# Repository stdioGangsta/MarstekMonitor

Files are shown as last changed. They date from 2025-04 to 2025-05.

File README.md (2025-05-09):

# MarstekMonitor

Small device with integrated display to monitor Marstek Venus battery systems.

Works on the 5.12kWh and 2.56kWh Marstek Venus battery.

Thanks to Superduper1969 and Tweakers (in Dutch) for EPSHome config and Modbus communication.

https://gathering.tweakers.net/forum/list_messages/2282240/0

WARNING:
Marstek has different versions of the Venus battery systems. The pinout of the RS485 connector is slightly different.
Currently, MarstekMonitor only supports Gen1 out of the box. Future versions will support all currently known models.

## Main features
-Plugs directly into the RS485 port on the side of the battery

-Easy configuration via ESPHome (and connection to Home Assistant)

-Display shows:

Battery Operating Mode (Idle, Charge, Discharge)

Charge/Discharge power

Battery SoC (State of Charge)

Charging Strategy (Auto, AI, Custom)

-No separate power supply needed

-(optional) Can be connected to WiFi to monitor/control the battery remotely (eg. Home Assisstant)\
The device is fully functional without a WiFi connection.

## What's in this repository?
#### Enclosure
Drawing of enclosure for the MarstekMonitor (behuizing) ( Both FreeCAD 0.21 and ready-to-3D-print .STL files)

#### HW
KiCAD 9.0 schematic and board files, including footprints for the used modules
#### SW
ESPHome yaml file

## HW v0.1
HW v0.1 is meant to be a proof of concept only. It consists of nothing more than a carrier board for the various modules.

09-04-2025: v0.1 assembled and working! There are a few minor issues that will be solved in the next version. See below.

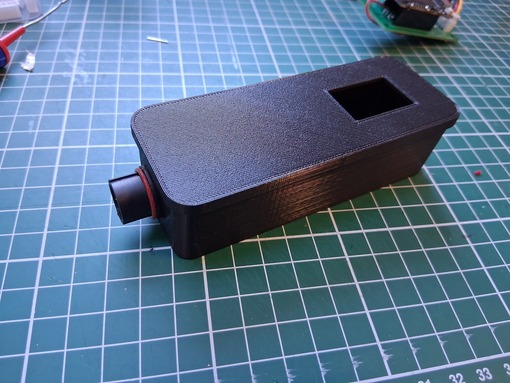
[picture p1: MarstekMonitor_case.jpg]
case

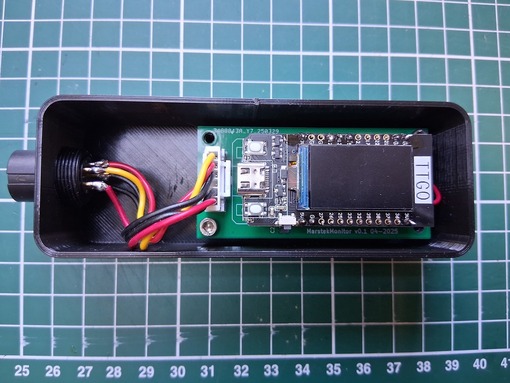
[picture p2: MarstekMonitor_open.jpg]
open

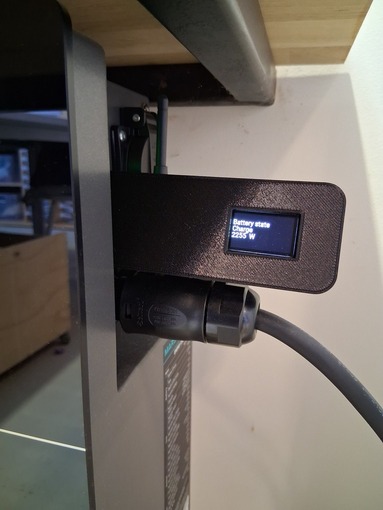
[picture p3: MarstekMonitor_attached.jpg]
attached


Partlist:
1. MarstekMonitor v0.1 PCB 
2. LilyGo ESP32 T-Display v1.1 [link](https://www.tinytronics.nl/en/development-boards/microcontroller-boards/with-wi-fi/lilygo-ttgo-t-display-v1.1-esp32-with-1.14-inch-tft-display "Webshop").
3. Buck-Boost converter [link](https://www.tinytronics.nl/en/power/voltage-converters/buck-boost-(step-up-down)-converters/dc-dc-step-up-down-buck-boost-converter-0.6a-5v-output "Webshop").
4. RS485-Serial module [link](https://nl.aliexpress.com/item/1005008217845791.html)
5. 3d Printed enclosure 
6. RS485 Connector: Weipu SP17, 5pin male connector. This connector is supplied with the Marstek battery

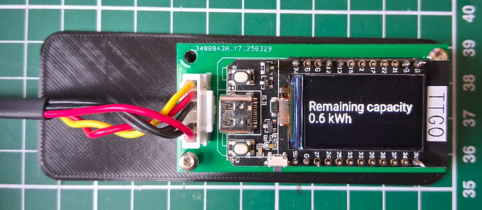
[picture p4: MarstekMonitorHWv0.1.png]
HW V0.1


### Known issues with HW v0.1
These will be solved in the next HW iteration
1. GPIO12 used for RS485. GPIO12 is an ESP32 strapping pin. This can cause issues on reset.
2. Switch to right-angle JST-XH connector
3. Footprint for Buck-boost and RS485 module: TH diameter slighty too small. Modules fit, but need to be forced in.
4. Silkscreen for Lilygo T-display does not match actual footprint
5. Panel mount Weipu 6p connector does not seem to exist.

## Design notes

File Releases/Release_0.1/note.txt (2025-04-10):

Release note for v0.1
!! v0.1 is not a stable release and is not recommended for end users !!

HW v0.1 contains no 3D printed enclosure and is only for proof-of-concept testing
The PCB has a known issue: The RX pin on T-DISPLAY ESP32 uses GPIO12. This is also a strapping pin and can lead to problems

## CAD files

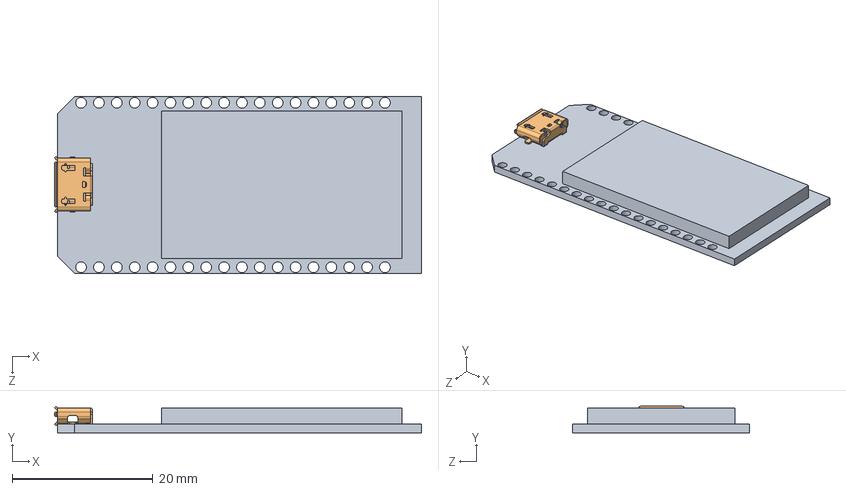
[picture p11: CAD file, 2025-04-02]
HW/ttgo-tdisplay-kicad-master/TTGO1.SLDASM
52.1 x 3.77 x 25.1 mm
TTGO-ESP32LORA
microusb

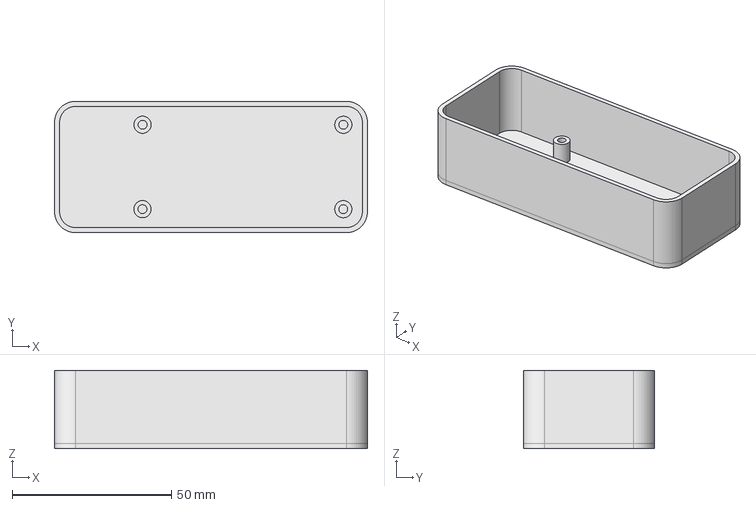
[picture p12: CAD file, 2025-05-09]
Enclosure/MarstekMonitorEnclosureV1.FCStd
98.2 x 41.2 x 24.6 mm

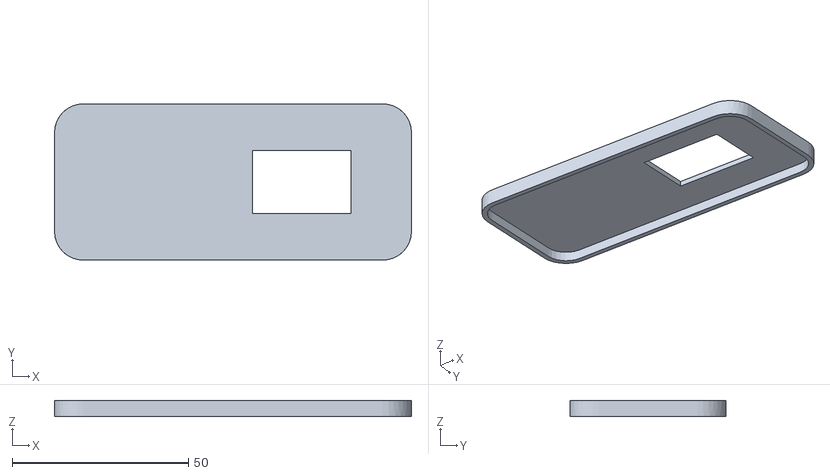
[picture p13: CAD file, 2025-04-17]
Enclosure/MarstekMonitorEnclosureV1Deksel.stl
101.4 x 44.4 x 4.60

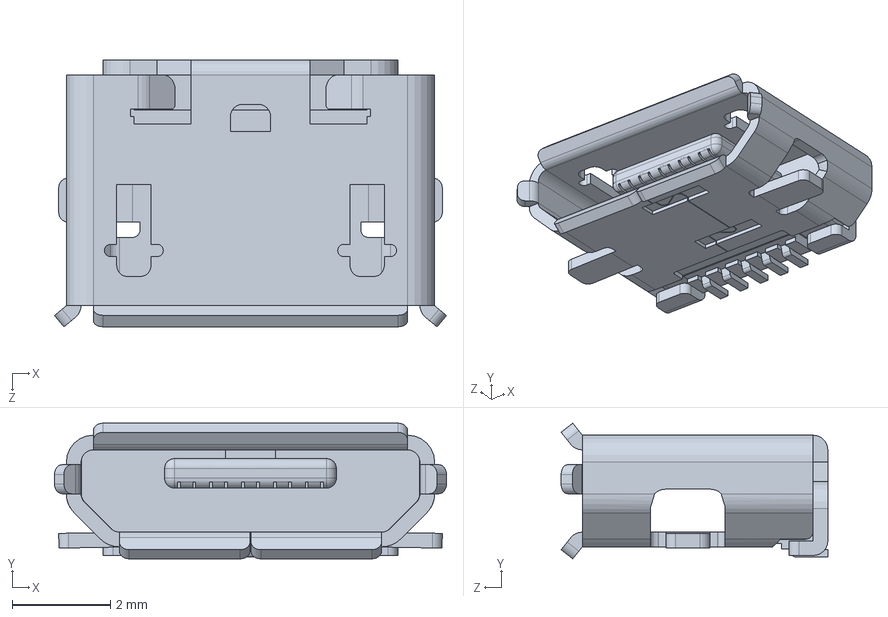
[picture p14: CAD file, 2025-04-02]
HW/ttgo-tdisplay-kicad-master/microusb.SLDPRT
7.98 x 2.76 x 5.43 mm

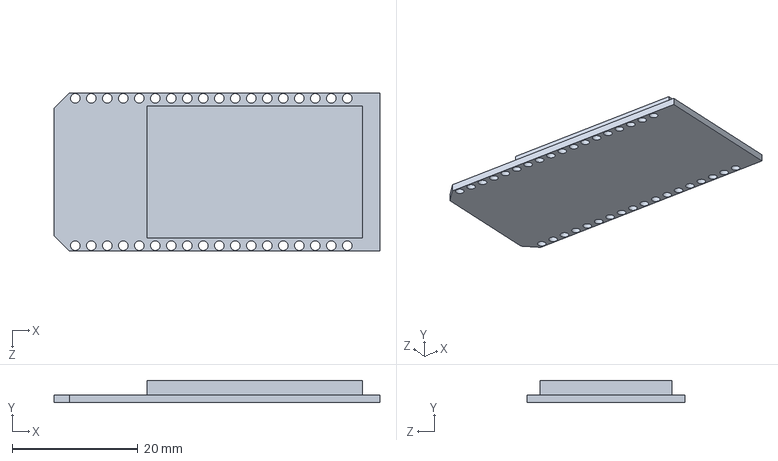
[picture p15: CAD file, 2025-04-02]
HW/ttgo-tdisplay-kicad-master/TTGO-ESP32LORA.SLDPRT
51.8 x 3.55 x 25.1 mm

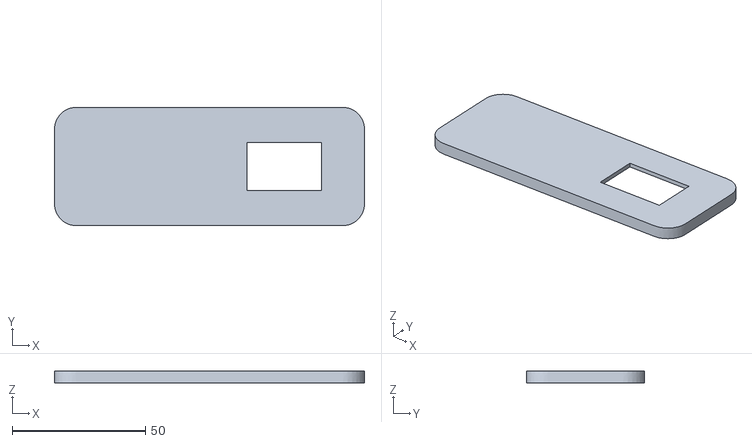
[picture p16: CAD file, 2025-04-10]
Enclosure/MarstekMonitorEnclosureV0Deksel.stl
116.4 x 44.4 x 4.60

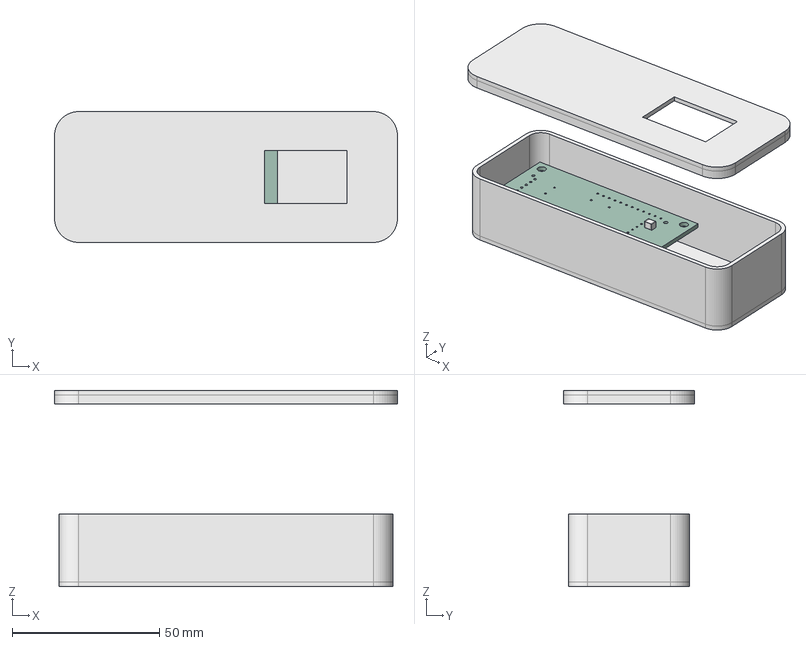
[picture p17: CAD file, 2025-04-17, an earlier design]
Enclosure/MarstekMonitorEnclosureV0.1.FCStd
116.4 x 44.4 x 66.6 mm
Doos
Deksel
C_1210_3225Metric
C_1210_3225Metric001
MarstekMonitor_PCB

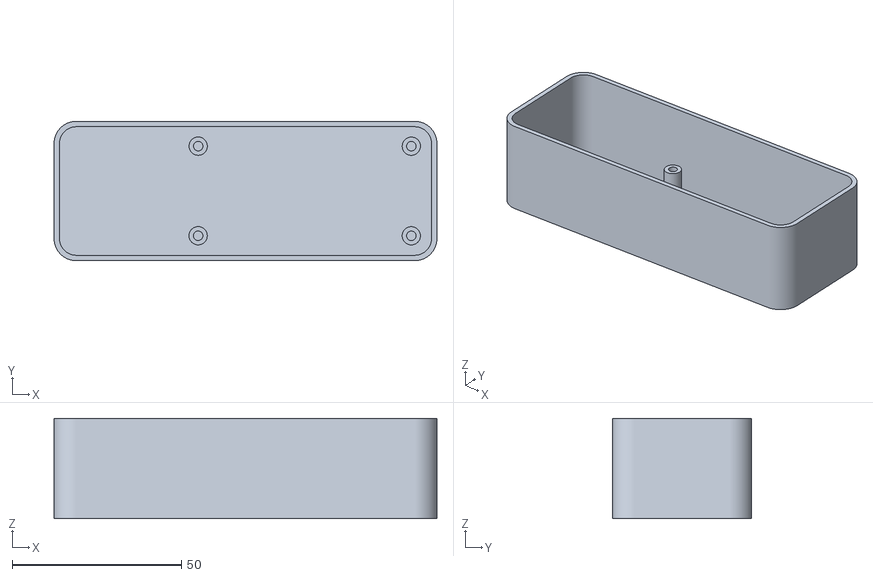
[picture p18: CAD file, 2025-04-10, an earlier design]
Enclosure/MarstekMonitorEnclosureV0.stl
113.2 x 41.2 x 29.6

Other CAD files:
Enclosure/MarstekMonitorEnclosureV1.stl

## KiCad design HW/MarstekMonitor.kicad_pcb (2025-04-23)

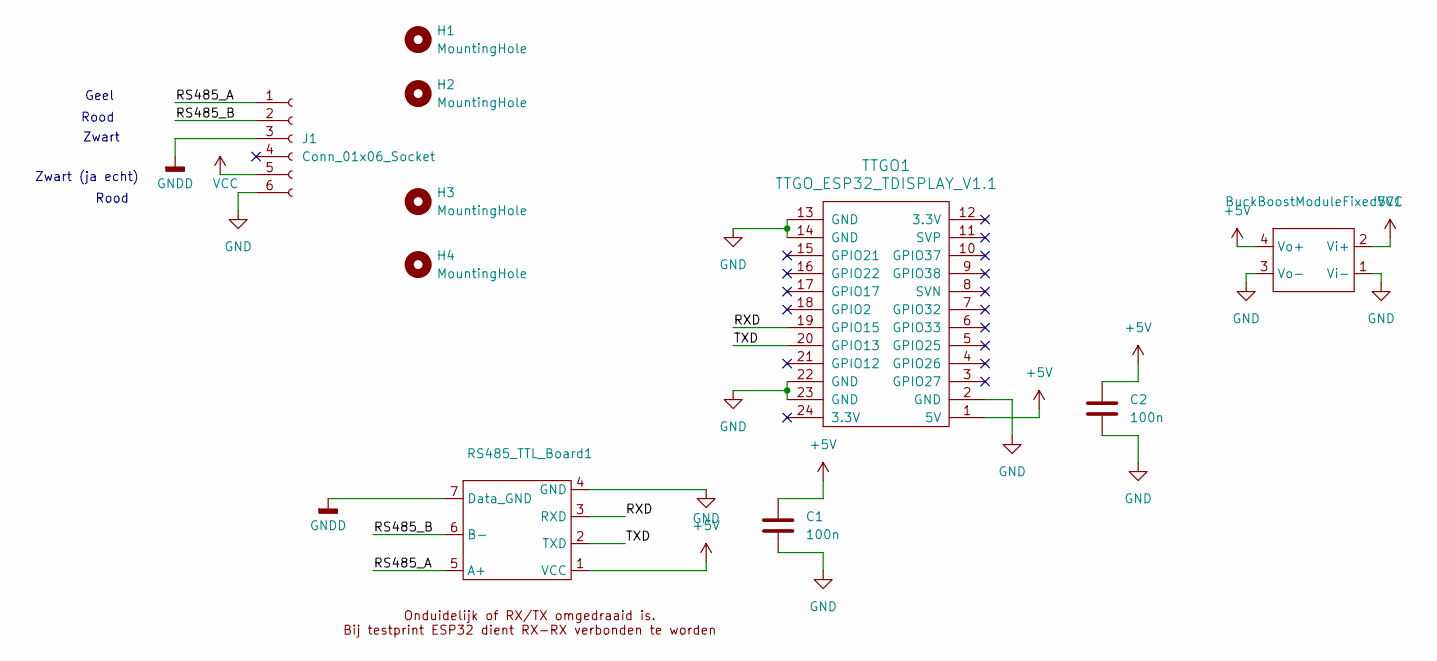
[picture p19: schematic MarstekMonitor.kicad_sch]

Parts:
BuckBoostModuleFixed5V1: buckboostmodule5V
C1, C2: 100n; C_1210_3225Metric_Pad1.33x2.70mm_HandSolder
H1, H2, H3, H4: MountingHole; MountingHole_3.2mm_M3
J1: Conn_01x06_Socket; JST_XH_B6B-XH-AM_1x06_P2.50mm_Vertical
RS485_TTL_Board1: RS485-TTL_module
TTGO1: TTGO_ESP32_TDISPLAY_V1.1; TTGO_ESP32_TDisplay_v1.1

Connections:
+5V: BuckBoostModuleFixed5V1.4 (Vo+), C1.1, C2.1, RS485_TTL_Board1.1 (VCC), TTGO1.1 (5V)
/RS485_A: J1.1, RS485_TTL_Board1.5 (A+)
/RS485_B: J1.2, RS485_TTL_Board1.6 (B-)
/RXD: RS485_TTL_Board1.3 (RXD), TTGO1.19 (GPIO15)
/TXD: RS485_TTL_Board1.2 (TXD), TTGO1.20 (GPIO13)
GND: BuckBoostModuleFixed5V1.1 (Vi-), BuckBoostModuleFixed5V1.3 (Vo-), C1.2, C2.2, J1.6, RS485_TTL_Board1.4 (GND), TTGO1.2 (GND), TTGO1.13 (GND), TTGO1.14 (GND), TTGO1.22 (GND), TTGO1.23 (GND)
GNDD: J1.3, RS485_TTL_Board1.7 (Data_GND)
VCC: BuckBoostModuleFixed5V1.2 (Vi+), J1.5

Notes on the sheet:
Rood
Geel
Zwart (ja echt)
Zwart

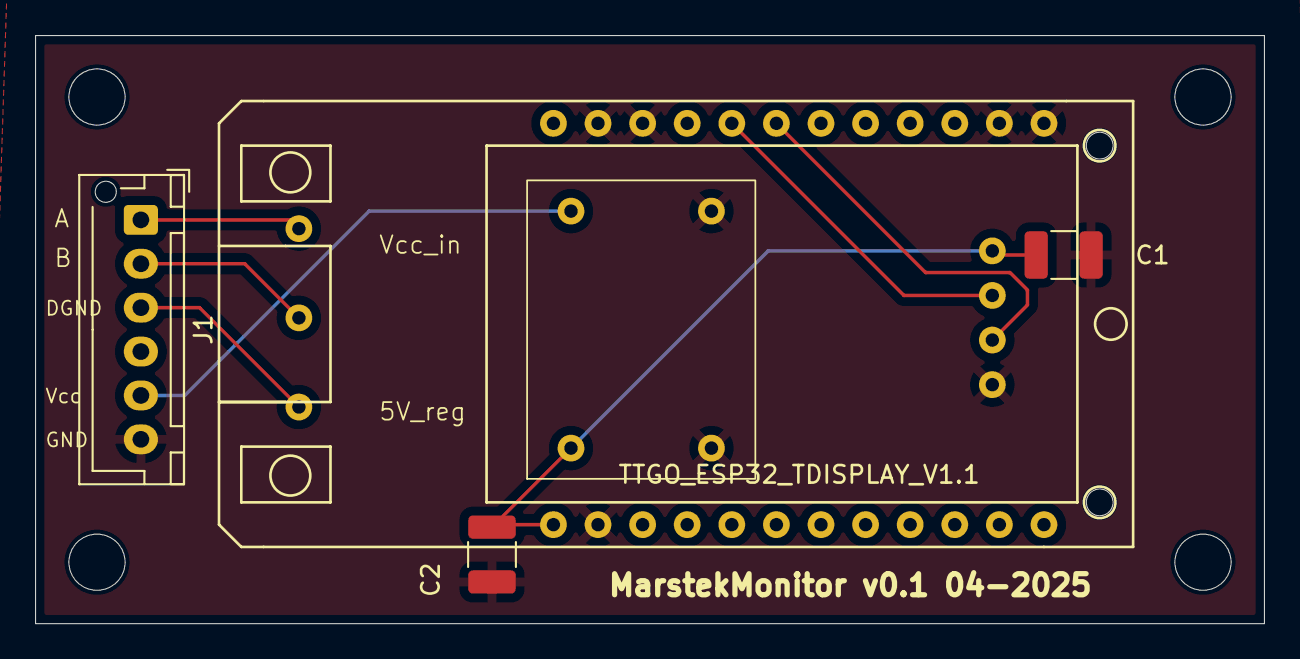
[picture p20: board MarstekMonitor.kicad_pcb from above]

Board: 2 copper layers, 70.0 x 33.5 mm, 10 parts (1 on the bottom side), 8 nets.

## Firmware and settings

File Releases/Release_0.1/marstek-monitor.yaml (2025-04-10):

# FOR MARSTEK v0.1 HW VERSION ONLY.
# NOT A STABLE VERSION
# THIS VERSION HAS KNOWN ISSUES, USE AT OWN RISK

#Only applicable to LilyGo T-Display V1.1 ESP32 devboard
esphome:
  name: marstek-monitor
  friendly_name: marstek-monitor

esp32:
  board: esp32dev
  framework:
    type: arduino

# Enable logging
logger:
   level: INFO
   baud_rate: 0

# Enable Home Assistant API
api:
  encryption:
    key: !secret marstek_api_key

ota:
  - platform: esphome
    password: !secret marstek_ota_key

wifi:
  ssid: !secret wifi_ssid
  password: !secret wifi_password

  # Enable fallback hotspot (captive portal) in case wifi connection fails
  ap:
    ssid: "Marstek-Monitor2"
    password: "marstekMon"

#captive_portal:
  #leeg

web_server:
  local: true
  port: 80
    
# Include custom fonts
font:
  - file: "gfonts://Roboto"
    id: roboto
    size: 26

  - file: "gfonts://Roboto"
    id: roboto_small
    size: 14

#Display backlight
output:
  - platform: ledc
    pin: 4
    id: gpio_04_backlight_pwm

light:
  - platform: monochromatic
    output: gpio_04_backlight_pwm
    name: "Display Backlight"
    id: back_light
    restore_mode: ALWAYS_ON

# Define colors
color:
  - id: red
    red: 100%
    green: 0%
    blue: 0%
    white: 0%

  - id: green
    red: 0%
    green: 100%
    blue: 0%
    white: 0%

# Pins for Onboard display
spi:
  clk_pin: GPIO18
  mosi_pin: GPIO19

interval:
  - interval: 3s
    then:
      - display.page.show_next: shottimer_display
      - component.update: shottimer_display    

# render on the screen.
display:
  - platform: st7789v
    id: shottimer_display
    cs_pin: GPIO5
    dc_pin: GPIO16
    reset_pin: GPIO23
    backlight_pin: no
    model: TTGO TDisplay 135x240
    rotation: 90°
    pages:
      - id: page1
        lambda: |-
          it.printf(0, 40, id(roboto), "State of Charge");
          it.printf(0, 65, id(roboto), "%.0f  %%", id(marstek_soc).state);
      - id: page2
        lambda: |-
          it.printf(0, 20, id(roboto), "Battery state");
          it.printf(0, 45, id(roboto), "%s", id(marstek_inverter_state).state.c_str());
          it.printf(0, 70, id(roboto), "%.0f  W", id(marstek_battery_power).state);
      - id: page3
        lambda: |-
          it.printf(0, 40, id(roboto), "Remaining capacity");
          it.printf(0, 65, id(roboto), "%.1f kWh", id(marstek_remaining_capacity).state);    
      - id: page4
        lambda: |-
          it.printf(0, 10, id(roboto_small), "FW: %.0f", id(marstek_fw_version).state);
          it.printf(0, 20, id(roboto_small), "Temperature. %.0f C", id(marstek_internal_temperature).state);

# Configure UART
# WARNING For HW v0.1 GPIO12 is used for RX. This can lead to issues (strapping pin)
uart:
  - id: mod_bus
    rx_pin: GPIO12
    tx_pin: GPIO13
    baud_rate: 115200
    data_bits: 8
    stop_bits: 1
    parity: NONE

modbus:
  - uart_id: mod_bus
    id: modbus1
    send_wait_time: 200ms

modbus_controller:
  - id: mt
    address: 0x1
    modbus_id: modbus1
    command_throttle: 200ms
    update_interval: 5s

# Tekstsensoren
text_sensor:
  - name: "Marstek Device Name"
    platform: modbus_controller
    modbus_controller_id: mt
    register_type: holding
    address: 31000
    register_count: 10
    response_size: 20
    skip_updates: 60 # 5 minutes

  # - name: "Marstek SN Code"
  #   platform: modbus_controller
  #   modbus_controller_id: mt
  #   register_type: holding
  #   address: 31200
  #   register_count: 10
  #   response_size: 20
  #   skip_updates: 60 # 5 minutes

  - platform: template
    name: "Marstek Inverter State"
    lambda: |-
      switch (int(id(inverter_state).state)) {
        case 0: return std::string("Sleep");
        case 1: return std::string("Standby");
        case 2: return std::string("Charge");
        case 3: return std::string("Discharge");
        case 4: return std::string("Fault");
        case 5: return std::string("Idle");
        default: return std::string("Unknown");
      };
    update_interval: 5s
    id: marstek_inverter_state
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

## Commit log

2025-03-03 Update lilygo-rs485.yaml
    Added Binary Sensors
2025-03-05 Update lilygo-rs485.yaml
    Change update rate Power
2025-04-02 Initial commit for PoC.
    Includes ESPHome yaml and Kicad 9.0 design files for first version of carrier board
    [MarstekMonitor-B_Cu.gbl, MarstekMonitor-B_Mask.gbs, MarstekMonitor-B_Paste.gbp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]
2025-04-10 Enclosure v0.1
    [MarstekMonitorEnclosureV0.1.FCStd, MarstekMonitorEnclosureV0.stl]
2025-04-10 Added top to enclosure.
    [MarstekMonitorEnclosureV0.1.FCStd, MarstekMonitorEnclosureV0.stl, MarstekMonitorEnclosureV0Deksel.stl]
2025-04-17 Enclosure updated
    Enclosure made smaller (lower, shorter).
    [MarstekMonitorEnclosureV0.1.FCStd, MarstekMonitorEnclosureV1.stl, MarstekMonitorEnclosureV1Deksel.stl]
2025-04-23 PCB layout updated
    Fixed wrong GPIO pin for RX
    [MarstekMonitor.kicad_pcb, MarstekMonitor.kicad_sch, MarstekMonitorEnclosureV1.FCStd]
2025-05-09 Marstek Venus different versions
    [MarstekMonitorEnclosureV1.FCStd]
